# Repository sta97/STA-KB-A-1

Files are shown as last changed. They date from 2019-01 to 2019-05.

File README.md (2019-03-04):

# STA-KB-A-1
40% Split Ortholinear Keyboard with Kailh Choc sockets and OLED

Schematic and PCB for electronics is here: https://easyeda.com/sta97/STA-A-1

LCD/Display header has more pins than required to provide support for displays or accessories that require more pins than an Adafruit Monochrome 128x64 OLED.

List of parts

*Teensy 3.2
*1n4001 diodes
*dupont connectors and compatable ribbon cable
*switch plate(mine is laser cut 0.050in acrylic but other materials might work better)
*(to be continued...)

Update as of Feb 10th 2019: Prototype PCBs have been ordered. EasyEDA link should be accurate to ordered prototype. Working prototype should be assembled within a month.

Update Feb 24th: PCBs arrived and have been soldered. Test code functional.

Update Mar 2nd: left board assembled and working

Update Mar 3rd: full assembled and board working

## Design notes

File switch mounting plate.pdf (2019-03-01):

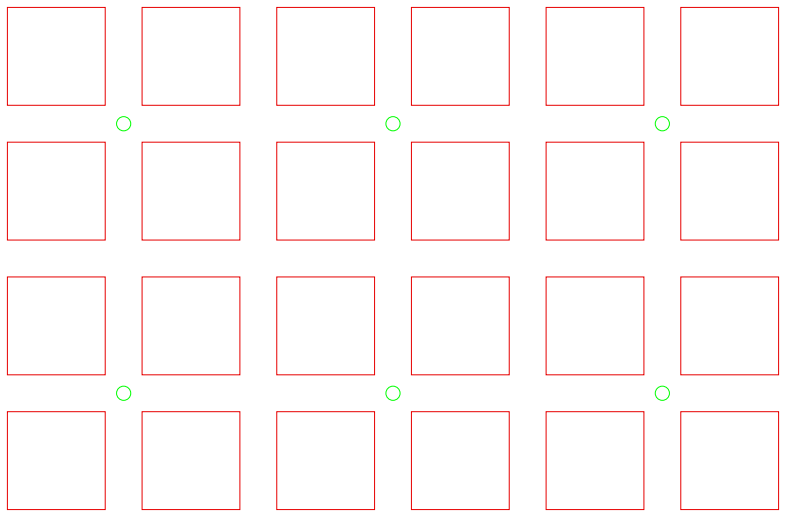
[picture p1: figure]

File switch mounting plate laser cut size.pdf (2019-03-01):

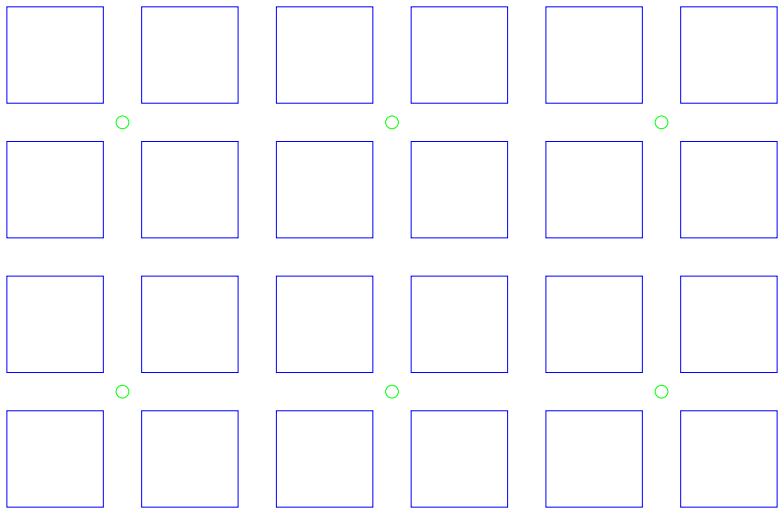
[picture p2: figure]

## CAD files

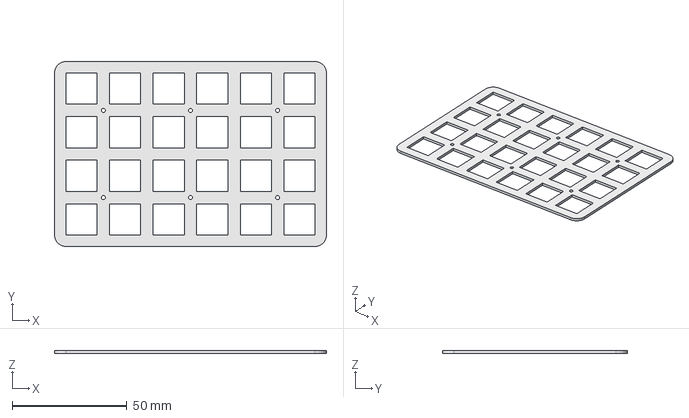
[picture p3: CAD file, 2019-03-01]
switch mounting plate laser cut size.FCStd
118.6 x 80.6 x 1.30 mm

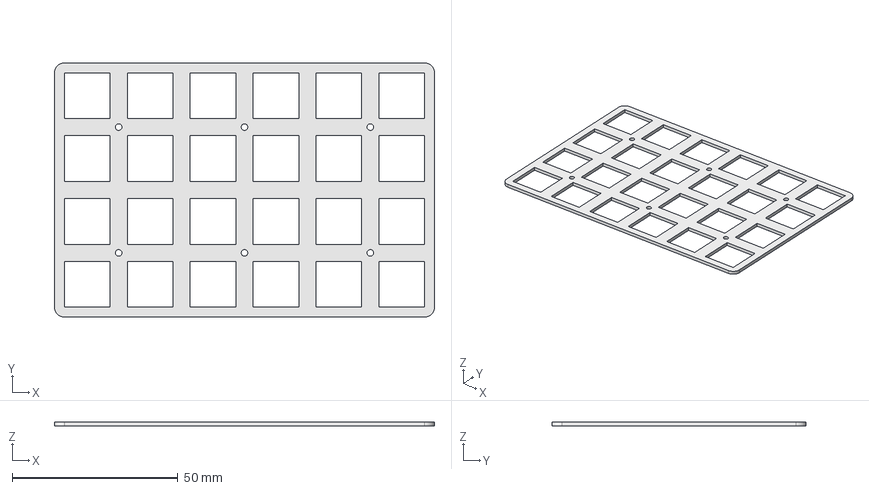
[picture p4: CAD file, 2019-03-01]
switch mounting plate.FCStd
114.8 x 76.8 x 1.30 mm

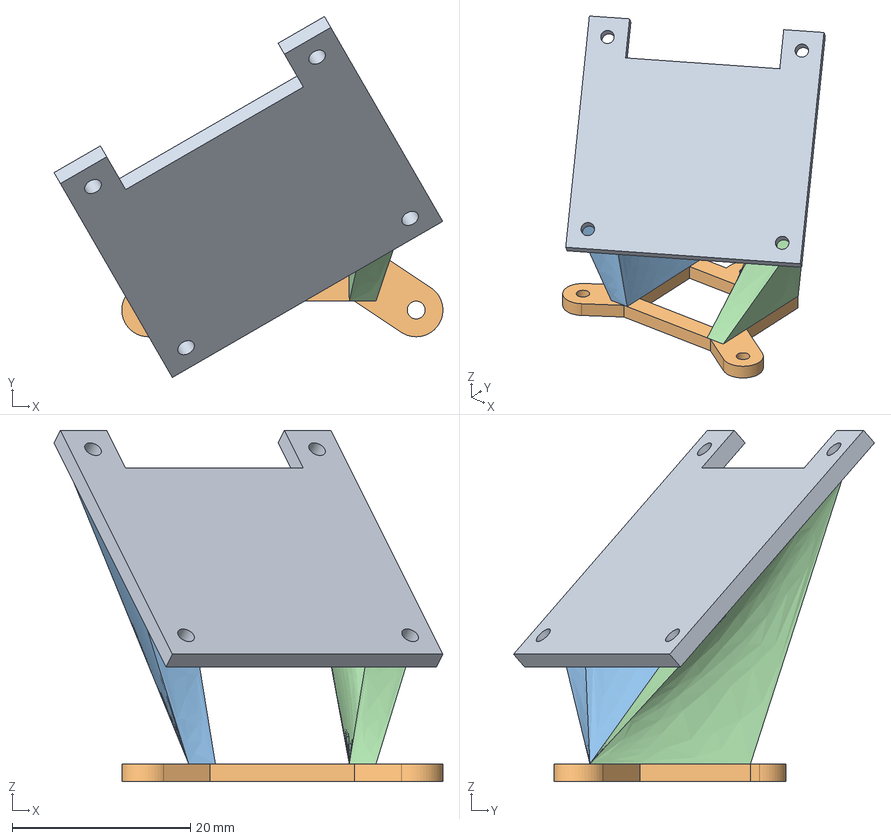
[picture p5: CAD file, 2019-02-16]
OLED mount.fcstd
43.6 x 40.5 x 39.4 mm
OLED mount
PCB mount
LoftLeft
LoftRight

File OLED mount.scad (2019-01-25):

display_hole_distance = 28.956;
pcb_hole_positions = [[0,10,0],[-15,-10,0],[15,-10,0]];
pcb_mount_size = [[0,15],[-20,-12.5],[20,-12.5]];
pcb_mount_thickness = [0,0,2];

pcb_mount();
translate([0,0,30]) display_mount();
attachment_curve();

module attachment_curve() {
     for(n = [0:100]) {
         t = n/100;
         translate([sin(t*180)*-20-18+t*3,t*-8,cos(t*180)*-15.5+15.5]) rotate([-45*t,180*t,30*t]) cube([2,25,2],true);
     }   
}

module pcb_mount() {
    difference(){
    cube([36,26,2],true);
       pcb_holes();
        cube([15,10,2.5],true);
    }
}

module pcb_holes() {
    translate(pcb_hole_positions[0]) hole();
    translate(pcb_hole_positions[1]) hole();
    translate(pcb_hole_positions[2]) hole();
}

module display_mount() {
    rotate([45,0,30]){
difference(){
cube([display_hole_distance+6,display_hole_distance+6,2],true);
    translate([0,display_hole_distance/2,0]) 
    cube([display_hole_distance-6,7,2.5],true);  
display_holes();
}
}
}

module display_holes() {
translate([display_hole_distance/-2,display_hole_distance/-2,0]){
hole();
translate([display_hole_distance, 0, 0]) {
    hole();
translate([0, display_hole_distance, 0]) {
    hole();
}
}
translate([0, display_hole_distance, 0]) {
    hole();
}
}
}

module hole() {
cylinder(h = 2.5, d = 2, center = true, $fn = 100);
}

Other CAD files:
OLED mount v2.stl
OLED mount.stl

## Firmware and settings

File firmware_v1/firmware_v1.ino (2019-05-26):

#include <SPI.h>
#include <Wire.h>
#include <Adafruit_GFX.h>
#include <Adafruit_SSD1306.h>

Adafruit_SSD1306 oled(128, 64, 19, 20, 21, 22, 23);

const int NUM_ROWS = 4;
const int NUM_COLS = 12;
const int row_pins[NUM_ROWS] = {0, 1, 2, 3};
const int col_pins[NUM_COLS] = {4, 5, 6, 7, 8, 9, 10, 11, 12, 14, 15, 16};

const uint16_t NOP = 0;
const uint16_t MODE_SWITCH = 0xFFFF;
const uint16_t PAUSE_SENDING = MODE_SWITCH-1;

/* modes will be added later. Modes will each have their own layers and logic so for example,
  the default layer for a WoW mode could have the actionbar keys moved down from the number row for reducing strain while another layer is for typing chat messages.
  Custom logic should allow modes to change layers in whatever way would be most useful, like a chat layer toggling on and off rather than having to hold a key down.
*/

/* example layer
  const int layer[NUM_COLS][NUM_ROWS] = {
  {0,0,0,0,0,0,  0,0,0,0,0,0},
  {0,0,0,0,0,0,  0,0,0,0,0,0},
  {0,0,0,0,0,0,  0,0,0,0,0,0},
  {0,0,0,0,0,0,  0,0,0,0,0,0},
  };
*/

const uint16_t layers[][NUM_ROWS][NUM_COLS] =
{
  {
    {KEY_ESC, KEY_Q, KEY_W, KEY_E, KEY_R, KEY_T,             KEY_Y, KEY_U, KEY_I, KEY_O,     KEY_P, KEY_BACKSPACE},
    {NOP, KEY_A, KEY_S, KEY_D, KEY_F, KEY_G,                 KEY_H, KEY_J, KEY_K, KEY_L,     KEY_ENTER, NOP},
    {MODIFIERKEY_SHIFT, KEY_Z, KEY_X, KEY_C, KEY_V, KEY_B,   KEY_N, KEY_M, MODIFIERKEY_GUI,  MODIFIERKEY_ALT, MODIFIERKEY_CTRL, MODIFIERKEY_RIGHT_SHIFT},
    {KEY_1, KEY_2, KEY_3, KEY_4, KEY_SPACE, KEY_5,           NOP, KEY_6, KEY_7, KEY_8, KEY_9,     KEY_0},
  },
  {
    {NOP, KEY_QUOTE, NOP, NOP, NOP, KEY_TAB,                             NOP, NOP, KEY_EQUAL, KEY_LEFT_BRACE, KEY_RIGHT_BRACE, KEY_DELETE},
    {NOP,  NOP, NOP, NOP,  NOP, NOP,    NOP, NOP, NOP, NOP, KEY_PRINTSCREEN, NOP},
    {NOP, NOP, NOP, NOP, NOP,        NOP, NOP, NOP, NOP, NOP, NOP},
    {KEY_PERIOD, NOP, NOP, NOP, NOP, KEY_COMMA,               NOP, NOP, NOP, KEY_HOME, KEY_PAGE_DOWN, KEY_END}
  },
  {
    {NOP, NOP, KEY_UP, NOP, NOP, NOP, NOP,                   NOP, KEY_BACKSLASH, NOP, NOP, KEY_DELETE},
    {NOP, KEY_LEFT, KEY_DOWN, KEY_RIGHT, NOP, NOP,                NOP, NOP, NOP, NOP, NOP, NOP},
    {NOP, NOP, NOP, NOP, NOP, NOP,              NOP, NOP, NOP, NOP, NOP, NOP},
    {KEY_SLASH, NOP, NOP, NOP, NOP, KEY_MINUS,       NOP, NOP, NOP, KEY_MEDIA_VOLUME_DEC, KEY_MEDIA_MUTE, KEY_MEDIA_VOLUME_INC},
  },
  {
    {KEY_F1, KEY_F2, KEY_F3, KEY_F4, KEY_F5,       KEY_F6, KEY_F7, KEY_F8, KEY_F9, KEY_F10, KEY_F11, KEY_F12},
    {NOP, NOP, NOP, NOP, NOP, NOP,            NOP, NOP, NOP, NOP, NOP, NOP},
    {NOP, NOP, NOP, NOP, NOP, NOP,                NOP, NOP, NOP, NOP, NOP, NOP},
    {NOP, NOP, NOP, NOP, NOP, KEY_SEMICOLON,     NOP, NOP, MODE_SWITCH, NOP, NOP, NOP},
  }
};

unsigned layer = 0;
unsigned mode = 0;

bool new_state[NUM_ROWS][NUM_COLS] = {
  {false, false, false, false, false, false,   false, false, false, false, false, false},
  {false, false, false, false, false, false,   false, false, false, false, false, false},
  {false, false, false, false, false, false,   false, false, false, false, false, false},
  {false, false, false, false, false, false,   false, false, false, false, false, false}
};

bool old_state[NUM_ROWS][NUM_COLS] = {
  {false, false, false, false, false, false,   false, false, false, false, false, false},
  {false, false, false, false, false, false,   false, false, false, false, false, false},
  {false, false, false, false, false, false,   false, false, false, false, false, false},
  {false, false, false, false, false, false,   false, false, false, false, false, false}
};

void setup_matrix() {
  for (int i = 0; i < NUM_ROWS; ++i) {
    pinMode(row_pins[i], INPUT_PULLUP);
  }

  for (int i = 0; i < NUM_COLS; ++i) {
    pinMode(col_pins[i], OUTPUT);
    digitalWrite(col_pins[i], HIGH);
  }
}

void setup() {
  setup_matrix();
  oled.begin();
  oled.clearDisplay();
  oled.display();
}

void read_matrix(void) {
  for (int row = 0; row < NUM_ROWS; ++row) {
    for (int col = 0; col < NUM_COLS; ++col) {
      digitalWrite(col_pins[col], LOW);
      new_state[row][col] = !digitalRead(row_pins[row]);
      digitalWrite(col_pins[col], HIGH);
    }
  }
}

void update_state(void) {
  for (int row = 0; row < NUM_ROWS; ++row) {
    for (int col = 0; col < NUM_COLS; ++col) {
      old_state[row][col] = new_state[row][col];
    }
  }

  read_matrix();
}

void remove_keys() {
  for (int row = 0; row < NUM_ROWS; ++row) {
    for (int col = 0; col < NUM_COLS; ++col) {
      if (!new_state[row][col])
        for (int i = 0; i < 4; ++i) //clear everything so keys aren't stuck on from layer switch.
          Keyboard.release(layers[i][row][col]);
    }
  }
}

void add_keys() {
  for (int row = 0; row < NUM_ROWS; ++row) {
    for (int col = 0; col < NUM_COLS; ++col) {
      if (!old_state[row][col] && new_state[row][col])
        Keyboard.press(layers[layer][row][col]);
    }
  }
}

void set_layer() {
  layer = 0;
  if (new_state[1][0])
    layer = layer | 1;
  if (new_state[1][11])
    layer = layer | 2;
}

void keyboard_logic() {
  set_layer();

  //Old keys must be removed before new keys are added so there is space in array for new key presses.
  remove_keys();

  add_keys();
}

void loop() {
  update_state();

  keyboard_logic();

  Keyboard.send_now();

  delay(50);
  /*
    oled.clearDisplay();

    oled.setTextSize(1);
    oled.setTextColor(WHITE);yyyyyyyyyyyyyyyyyyyyyyyyyyyyyyyyyyyyyyyyyyyyyyyyyyyyyyyyyyyyyyyyyyyy
    oled.setCursor(0, 24);

    for (int row = 0; row < NUM_ROWS; ++row) {
      for (int col = 0; col < NUM_COLS; ++col) {
        const int x = row * 5;
        const int y = col * 5 + (col > 5 ? 5 : 0);
        oled.drawRect(y, x, 5, 5, WHITE);
        if (new_state[row][col])
          oled.fillRect(y + 1, x + 1, 3, 3, WHITE);
      }
    }

    oled.print("layer ");
    oled.println(layer);

    for (int i = 0; i < 6; ++i) {
      oled.print(keyboard_keys[i]);
      if (i < 5)
        oled.print(",");
    }

    oled.display();
  */
}

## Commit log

2019-01-24 work started on OLED mounting bracket
    [OLED mount.scad]
2019-01-25 finished prototype version 1 of OLED mount
    [OLED mount.scad, OLED mount.stl]
2019-01-25 added link to schematic and PCB to readme
2019-01-25 changed hole size for display pins
    [OLED mount.scad, OLED mount.stl, STA-KB-A-1-PCB.kicad_pcb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]
2019-02-10 updated readme with current status
2019-02-16 designed oled mount in freecad
    [OLED mount v2.stl, OLED mount.fcstd]
2019-02-27 first version of swtich mounting plate
    [switch plate v1.dxf]
2019-03-01 updated switch plate to correct hole sizes
    [switch mounting plate.FCStd, switch plate v1.dxf]
2019-03-01 created laser cut version of mounting plate
    [switch mounting plate laser cut size.FCStd]
2019-03-01 new laser cut version
2019-03-05 fixed issue where gui key was activating on all layers
    [firmware_v1.ino]
